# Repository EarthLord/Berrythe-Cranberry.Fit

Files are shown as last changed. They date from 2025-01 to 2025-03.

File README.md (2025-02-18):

# Berrythe

## Objective

Create a low-cost alternative for a breathing assistant toy in India by replacing the circuitry of a night light toy. The working is similar these toys in these Amazon US [shopping link 1](https://a.co/d/hcPQM95), [shopping link 2](https://a.co/d/2bBX1N4). Below is a video of the resulting breathing sequence from a retrofit night light toy.

https://github.com/user-attachments/assets/268d343a-7a08-4612-9922-748c09accf75

This open-source project is done for [Cranberry.fit](https://cranberry.fit), a company developing personalized care products to improve menstrual health.

## Repository Content

This repository contains both the hardware and firmware for Berrythe - KiCad PCB design and TI Code Composer Studio Project. The respective hardware and firmware folders contain their documentation as well.

## Specifications of toy

1. Overall, the two functional modes are
    1. Breathing mode of 4, 7, 8
    2. Yellow night light mode
2. This needs to be compatible with the toys below (Amazon India [shopping link 1](https://amzn.in/d/7s0jjhx), [shopping link 2](https://amzn.in/d/guYvsHx))

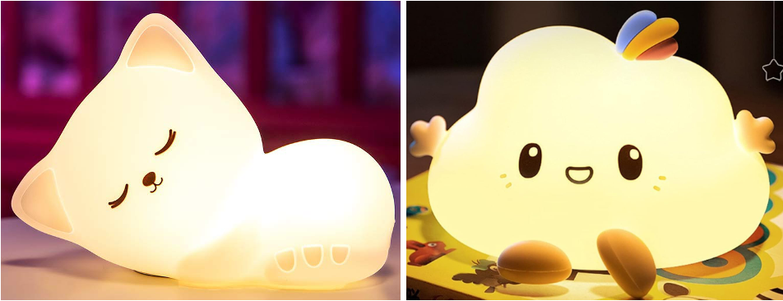
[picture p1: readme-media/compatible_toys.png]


3. Additional cost for the electronics at quantity of 1000 needs to be less than 300 INR.
4. Battery life
    1. Breathing or Night light mode need needs to be able to run at least for 8 hours on a full charge.
    2. In OFF mode the battery should last at least 6 months.

### Operations of the toy

1. Overall there are three modes for the toy, namely
    1. Power down mode (OFF)
    2. Breathing mode (BREATH)
    3. Yellow night light mode (NIGHT)
2. There is one button for user input interaction, at the bottom of the toy. The two means of interaction with this button is single-press or double-press. Double press isn’t used as it reduces good user experience. 
3. The breathing mode will be on for a time of 10 minutes, following which it’ll power down.
4. The night light mode will be on for a time of 30 minutes, following which it’ll power down.
5. The following will be the flow of operation of the toy

```mermaid
stateDiagram
  direction LR
  [*] --> OFF
  OFF --> BREATH:1-press
  BREATH --> NIGHT:1-press
  BREATH --> OFF:10 min
  NIGHT --> OFF:30 min
  NIGHT --> OFF:1-press
```
6. The breathing mode timing would be as follows to provide an overall 4, 7, 8 breathing exercise. The green and blue color intensity would change as shown below, visually changing linearly. 



| Inhale | Tr | Hold | Tr | Exhale | Tr |
| --- | --- | --- | --- | --- | --- |
| 3.8s | 0.2s | 6.8s | .2s | 7.8s | 0.2s |
7. During the transition time of 0.2s (Tr in above table) the color will shift from previous one to the next one.

## Breathing Technique’s Why and How

### Slow, controlled breathing stimulates the parasympathetic nervous system

This is the part of the nervous system that slows down activity in the body, promotes relaxation, and thus alleviates anxiety and mood changes

### Slows down heart rate, blood pressure, and oxygen consumption

This breathing technique has a low inhale-to-exhale ratio (where you only inhale for 4 seconds and exhale for 8), and requires you to hold your breath. These specific practices may increase your blood oxygen levels and lower your blood pressure. All of which contribute to a less agitated, and more relaxed state.

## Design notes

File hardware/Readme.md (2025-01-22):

# Berrythe hardware documentation

This is the hardware setup of V1 of Berrythe. The white PCB is the original PCB from the night light toy. [LP-MSPM0C1104](https://www.ti.com/tool/LP-MSPM0C1104) development kit has a XDS110 debugger and is used to program, debug and log UART to PC.

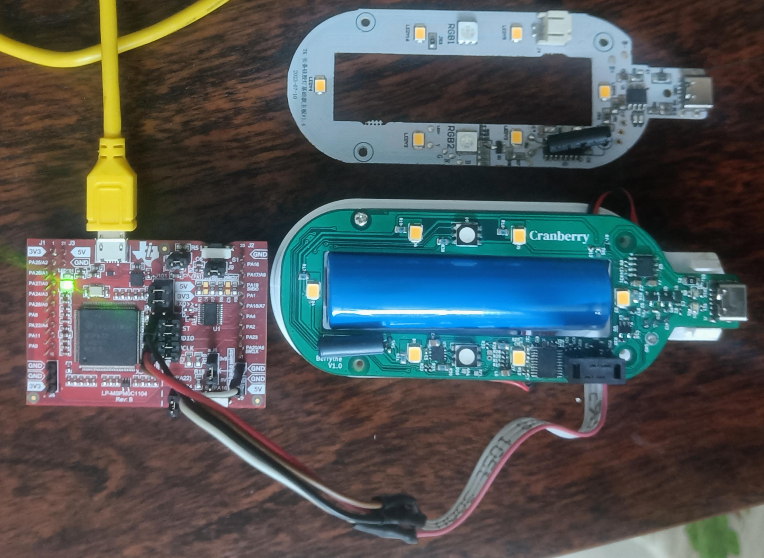
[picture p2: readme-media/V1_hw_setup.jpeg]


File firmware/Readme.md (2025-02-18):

# Berrythe firmware documentation

The overarching requirement from the firmware is specified by the state machine below.
```mermaid
stateDiagram
  direction LR
  [*] --> BREATH:Boot
  OFF --> [*]:Button press<br>to reboot
  BREATH --> NIGHT:Button press
  BREATH --> OFF:10 min
  NIGHT --> OFF:30 min
  NIGHT --> OFF:Button press
  LOW_BATTERY --> OFF:Red LED<br>indication
  NIGHT --> LOW_BATTERY: Vbat<3.5V
  BREATH --> LOW_BATTERY: Vbat<3.5V
```
## Challenges

### Code memory size
[MSPM0C1103](https://www.ti.com/product/MSPM0C1103), the target micro-controller from TI is with a ARM Cortex M0+ processor, 1 kB RAM and 8 kB Flash as it is targeted for low-cost, simple applications. The primary challenge for the firmware was to develop the application within the code space available in Flash, especially the LED gamma correction algorithm explained below. The memory usage (-Os optimization) is as shown in the table below, although it might change a bit based on the commit.

| Memory | Usage |
| --- | ----- |
| RAM (1 kB) | 12% |
| Flash (8 kB) | 84% |

### Gamma correction
Getting gamma correction to have pleasant visual transitions of LEDs and to have it fit in the 8 kB of flash needed iterations in the design. This is explained in detail further down.

## Project specific development principles
- Keep it simple - develop what's necessary for the project, not more. This project is not going to be a library for further use.
    - Important for both reliability and memory optimization.
- Use as much as possible vendor HAL driver and suitable external libraries. This would be the DriverLib from TI and  printf from Spare Time Labs 2.0.
    - One implication of this would be majority of the configuration of the peripherals of the is based on the System Configuration GUI tool from TI. The configuration is stored in a .syscfg file. Build triggers generation of a ti_msp_dl_config.c and .h file based on the .syscfg file.
- Optimize what is necessary, don't worry about the miniscule gains either in memory usage or power consumption.

## Low memory footprint printf library
Formatted prints over the UART line is an essential tool for debugging, even if the Code Composer Studio from TI along with XDS110 debugger provides complete debugging infrastructure of breakpoints, memory/variable views, and call-stacks.

[Tiny printf](http://www.sparetimelabs.com/tinyprintf/tinyprintf.php) from Spare Time Labs 2.0 is library being used, with it consuming 528 bytes on the Flash memory.

Alternatives considered were the [mpaland's printf fork maintained by eyalroz](https://github.com/eyalroz/printf) and [charlesnicholson's nanoprintf](https://github.com/charlesnicholson/nanoprintf). Both of them consume more memory than Tiny printf.

## BREATHE and NIGHT mode
The general flow of these two modes are as shown below.
```mermaid
flowchart TD
    enter(["Enter mode"]) ---> init["Mode specific<br>initialization"]
    init ---> timer["Set periodic<br>timer callback"]
    timer ---> sleep(["Sleep"])
    tim_cb(["Periodic timer<br>callback<br>Every millisecond"]) --> btn["Is button<br>pressed"]
    btn@{ shape: diam}
    btn --> |YES|next(["Start next<br>mode"])
    btn --> |NO|bat["Is<br>Bvat<3.5V"]
    bat@{ shape: diam}
    bat --> |YES|low(["Go to low<br>battery mode"])
    bat --> |NO|time["Is mode<br>timed out"]
    time@{ shape: diam}
    time --> |YES|off(["Go to low<br>OFF mode"])
    time --> |NO|mode["Mode specific<br>process"]
    mode --> sleep
```
Since in these modes the main power consumption is from the LEDs, there is less focus on optimizing the power consumption due to the MCU. The periodic timer callback wakes the MCU every millisecond. 

### BREATHE mode
Breathe mode is for the primary use of providing a breathing pattern for the user. Note that for the end user the color transition of green and blue need to appear to be changing linearly visually.
Color

|Color | Green | Purple | Blue |
|--- | ----- | --- | ---- |
|Duration | 4s | 7s | 8s |

LP5810 LED driver has an auto mode where the LED pattern needed can be programmed in it's registers via I2C, such that it can generate the pattern automatically without involvement of the MCU. This mode didn't work as expected as detailed in this [forum question](https://e2e.ti.com/support/power-management-group/power-management/f/power-management-forum/1463546/lp5810-auto-pattern-not-as-per-what-gui-shows/). Thus, the manual mode is used where every millisecond a I2C write sets the LED intensity to be set by LP5810.

As the flash memory is limited and only linear transitions of color is needed, an approach of interpolating the LED brightness for each sequence is done. This is done by specifying the start and end brightness for the red, green and blue LEDs, along with the duration of the period of this sequence in arrays. By tracking the number of periodic timer calls in each sequence, the current value to be set for each of the three LEDs is interpolated based on the start and end values.

#### Gamma Correction

A technique called Gamma Correction is need to correct the LED brightness as it is changes in to make the perception with our eyes linear. Adafruit has a good [practical article](https://learn.adafruit.com/led-tricks-gamma-correction) on this.

Gamma correction can be done by LP5810, although this feature is not used. This is because it has only a 8-bit value to work on. Since initially the value to be set is generated as a 16-bit value, gamma correction is also done with this and then down-scaled to 8 bit value. This creates a smoother transition. This helped in fixing the blocky transition of the colors when using the inbuilt gamma correction of LP5810. 

To avoid usage of float variables as well as 'to the power of' operation of floats, the gamma value used for gamma correction is 2.0. This would need additional 2-3 kB of libraries for the float operations and would exceed the 8kB flash size. Using a gamma value of 2 enables working only on integers and gives a decent gamma correction visually.

### NIGHT mode
In night mode one of the generic timers (TIMG) is used to operate the warm white LEDs at a 10% duty cycle. LP5810 is disabled on the start of this mode. 

## OFF mode and low power considerations
In all modes except OFF mode, the MCU operates in SLEEP mode, where only the processor 

| Mode | Low power | Operation |
| --- | ----- | ----- |
| Other modes | SLEEP0 | Only processor is disabled |
| OFF mode | STANDBY1  | Only GPIO and Timers (32kHz) are enabled |

Before initiating STANDBY1 low power state in the OFF mode, LP5810 is disabled and the MOSFET driving the night lights is turned off to remove their power consumption.

On waking up from OFF mode, the MCU does a software reset to start afresh in the BREATHE mode. This makes the firmware development easier since each mode's states don't have to be maintained across as they can be run at most once.

## Button sensing
To have better user experience, it was decided to only have user's perform a single press and not have any significance for double, triple or long press. For both debouncing and filtering out unintentional taps, the button press needed to be in the form of the below pattern. 

```mermaid
---
config:
  theme: neo
---
timeline
    At least 25 ms : Released
    At least 25 ms : Pressed
    At least 25 ms : Released
    100 ms : Valid button press
```

## Battery and charging check for low power mode
Voltage dividers are used to measure the battery voltage and the USB input voltage by the ADC of the MCU.  The different modes for the battery are computed as per the below table.

| State | USB Power | Battery voltage |
| ---- | --- | --- |
| CHARGING | Present | Don't care |
| NORMAL | Absent | Greater than 3.5V |
| LOW | Absent | Lower than 3.5V |

Battery and USB power measurements are done approximately every 16s. On sensing LOW battery state, irrespective of the current mode of operation, LOW_BATTERY mode is entered. In this mode a short 3s sequence of red LED flashing is shown to user to indicate the mode. After this it goes to the OFF mode to conserve battery power.

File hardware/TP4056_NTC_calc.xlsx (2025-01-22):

Vin | 5 | V
Vtemp,IH | 0.8 | V
Vtemp,IL | 0.45 | V
Rntc @ 25C | 10000 | Ohm
RH ntc @ 45C | 4911 | Ohm
RL ntc @ 2C | 25000 | Ohm
R1 | 300000 | Ohm
R2 | 18000 | Ohm
VtempIH eq | 0.7977819009
VtempIL eq | 0.4515138219

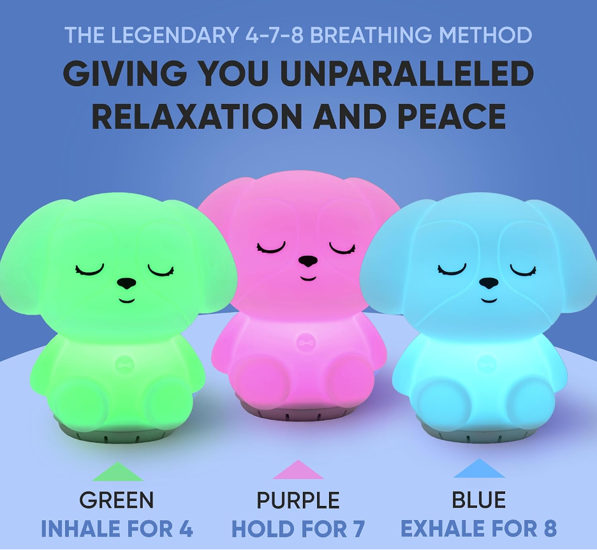
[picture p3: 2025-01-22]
readme-media/breathing_toys.png

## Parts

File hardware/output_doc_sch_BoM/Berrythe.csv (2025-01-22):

No | Reference | Value | Footprint | Qty | DNP | PN
1 | BT1 | Battery_Cell | Berrythe-footprints:JST_PH_S2B-PH-K_1x02_P2.00mm_Horizontal | 1 |  | S2B-PH-K-S
2 | C1,C2,C4,C6 | 10u | Berrythe-footprints:C_0805_2012Metric | 4 |  | CL21A106KOQNNNE
3 | C3,C5,C7,C9,C10,C14 | 100n | Berrythe-footprints:C_0402_1005Metric | 6 |  | CL05B104KO5NNND
4 | C8,C11,C12,C13 | 10n | Berrythe-footprints:C_0402_1005Metric | 4 |  | CL05B103KO5NNNC
5 | D1 | Green LED | Berrythe-footprints:LED_0603_1608Metric | 1 |  | QBLP601-YG1-2943
6 | D2 | Red LED | Berrythe-footprints:LED_0603_1608Metric | 1 |  | SML-D12U1WT86
7 | D3,D4,D5,D6,D7,D8 | Warm LED | Berrythe-footprints:LED_PLCC_2835 | 6 |  | JB2835BWT-N-U35EA0000-N000P001
8 | D9,D10 | RGB LED | Berrythe-footprints:LED_RGB_5050-6 | 2 |  | QLSP08RGB_B
9 | D11 | D5V0S1U2LP | Berrythe-footprints:D_SOD-882D | 1 |  | D5V0S1U2LP-7B
10 | J1 | USB_C_Receptacle_PowerOnly_6P | Berrythe-footprints:AMPHENOL_10164359-00011LF | 1 |  | 10164359-00011LF
11 | J2 | TactileSw Conn | Berrythe-footprints:Molex_Pico-Clasp_501331-0207_1x02-1MP_P1.00mm_Vertical | 1 |  | 530470210
12 | J3 | TactileSw Conn | Berrythe-footprints:Molex_PicoBlade_53047-0210_1x02_P1.25mm_Vertical | 1 |  | 5013310207
13 | Q1,Q2,Q3 | DMN2024U | Berrythe-footprints:SOT-23 | 3 |  | DMN2024U-7
14 | R1 | 0E | Berrythe-footprints:R_1206_3216Metric | 1 |  | RC1206JR-130RL
15 | R2,R6,R8,R9,R14,R15,R28,R29 | 2k | Berrythe-footprints:R_0402_1005Metric | 8 |  | RC0402FR-072KL
16 | R3 | 330E | Berrythe-footprints:R_0402_1005Metric | 1 |  | RC0402FR-07330RL
17 | R4,R5 | 5M1 | Berrythe-footprints:R_0402_1005Metric | 2 |  | RC0402FR-075M1L
18 | R10,R11,R12,R35 | 5k1 | Berrythe-footprints:R_0402_1005Metric | 4 |  | RC0402FR-075K1L
19 | R13,R26,R30,R31,R34 | 47k | Berrythe-footprints:R_0402_1005Metric | 5 |  | RC0402FR-0747KL
20 | R16,R17,R18,R19,R20,R21,R38,R39 | 24E | Berrythe-footprints:R_0805_2012Metric | 8 |  | RK73H2ATTD24R0F
21 | R22,R23,R24,R27,R32,R33 | 10E | Berrythe-footprints:R_0402_1005Metric | 6 |  | RC0402FR-0710RL
22 | R37 | 0E | Berrythe-footprints:R_0402_1005Metric | 1 |  | RC0402JR-070RL
23 | SW1 | SW_Vibr | Berrythe-footprints:SW-18010P | 1 |  | 1766
24 | U1 | BQ29737 | Berrythe-footprints:WSON-6_1.5x1.5mm_P0.5mm | 1 |  | BQ29737DSER
25 | U2 | TP4056 | Berrythe-footprints:SOIC-8-1EP_3.9x4.9mm_P1.27mm_EP2.41x3.3mm | 1 |  | TPB4056B2X-ES1R
26 | U3 | LP5810D | Berrythe-footprints:WSON8-LP5810 | 1 |  | LP5810DDSDR
27 | U4 | MSPS003FxSPW20R | Berrythe-footprints:TSSOP-20_4.4x6.5mm_P0.65mm | 1 |  | MSPS003F4SPW20R
28 | U5 | TCR2LF33,LM(CT | Package_TO_SOT_SMD:SOT-23-5 | 1 |  | TCR2LF33,LM(CT

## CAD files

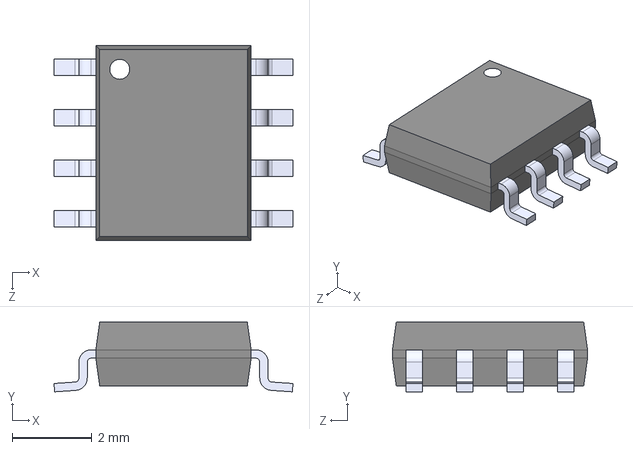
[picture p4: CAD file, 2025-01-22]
hardware/3D_models/TP4056-42-ESOP8.step
6.00 x 1.75 x 4.90 mm

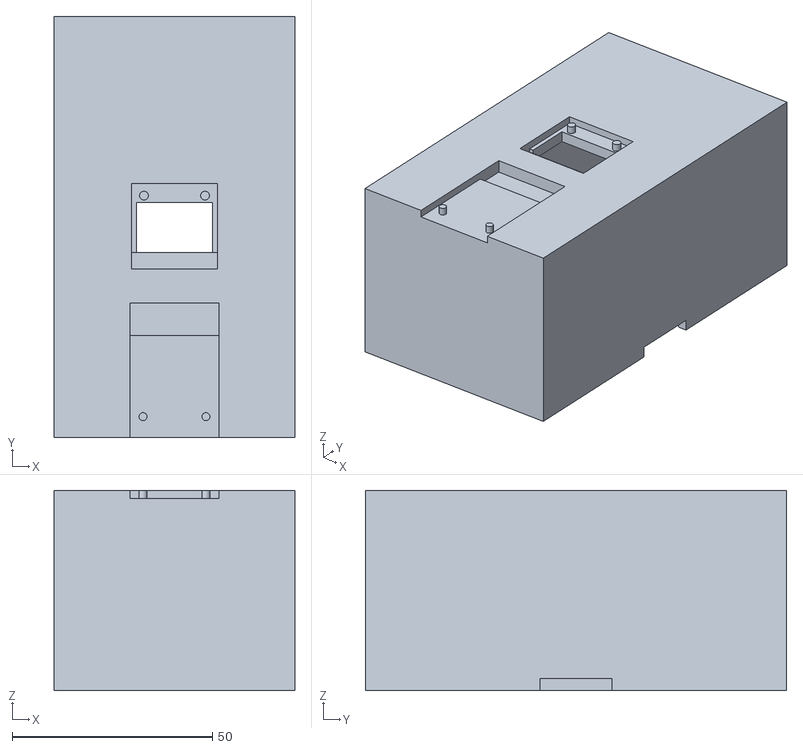
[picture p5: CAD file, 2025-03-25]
test-jig/Jig_PCB_holder_top.stl
60.0 x 105.0 x 50.0

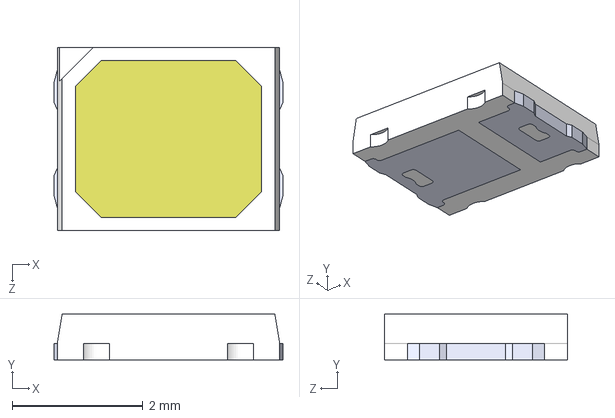
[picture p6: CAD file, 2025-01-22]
hardware/3D_models/JB2835BWT-3DModel.STEP
3.50 x 0.7 x 2.80 mm

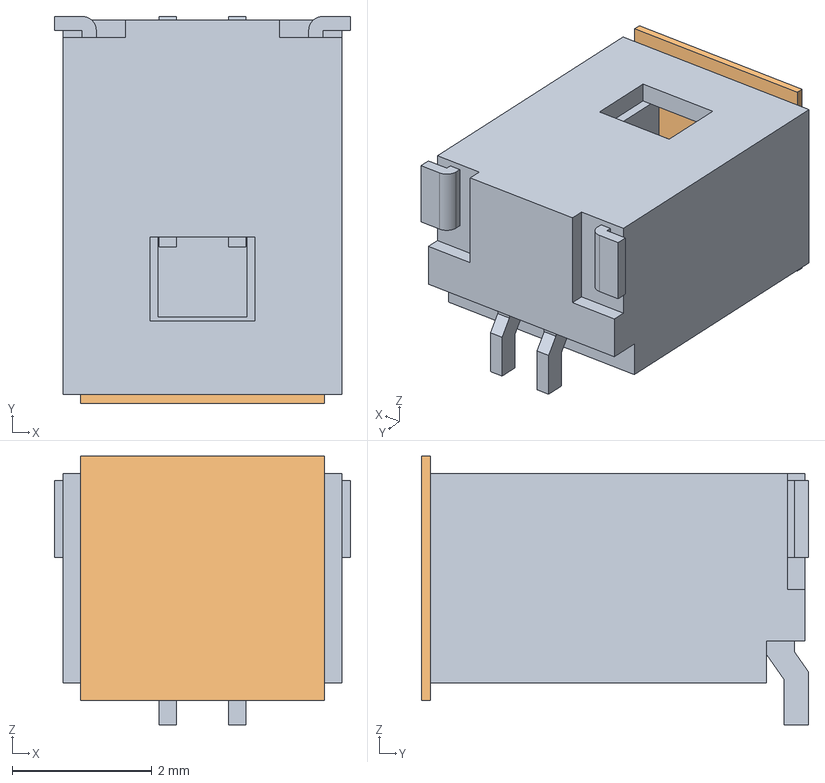
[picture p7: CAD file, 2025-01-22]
hardware/3D_models/5013310207.stp
4.24 x 5.54 x 3.85 mm

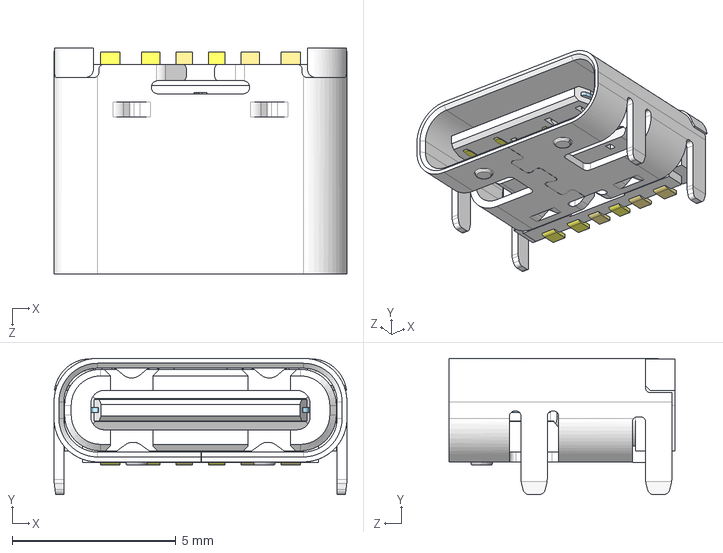
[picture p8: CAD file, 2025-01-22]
hardware/3D_models/10164359-00011LF.step
8.94 x 4.16 x 6.90 mm

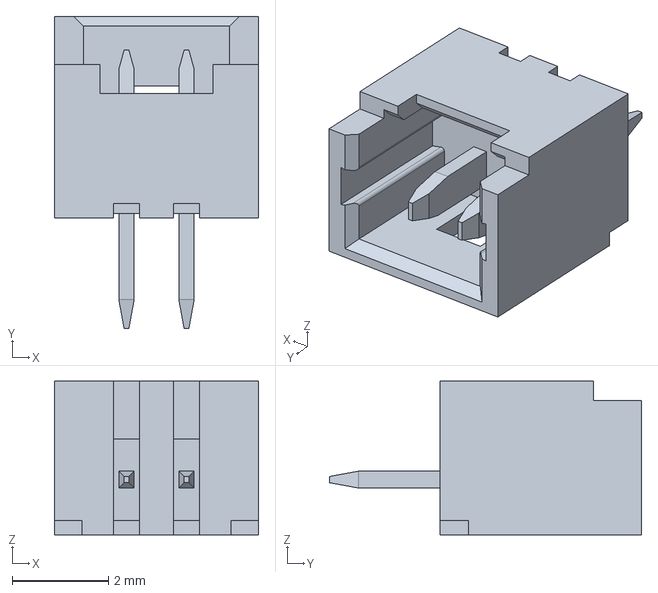
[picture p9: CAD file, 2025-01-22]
hardware/3D_models/530470210-3DModel.STEP
4.25 x 6.50 x 3.20 mm

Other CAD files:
test-jig/Jig_PCB_holder_bottom.FCStd
test-jig/Jig_PCB_holder_bottom.stl

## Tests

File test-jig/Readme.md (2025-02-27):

```mermaid
---
config:
  themeCSS: |
    #edge4, #edge6, #edge7, #edge8 { stroke: red; stroke-width: 2px; }
    #edge9 { stroke: green ; stroke-width: 2px;  stroke-dasharray="10,5"; }
---
stateDiagram
  direction LR
  idR --> XDS110:USB
  XDS110 --> Berrythe:SWD,UART
  idR --> Berrythe:Button GPIO
  idC --> idR:I2C
  idAC --> idP1:240V AC
  idR --> MOSFET:GPIO
  idP1 --> idR:5V
  idP1 --> MOSFET:5V
  MOSFET --> Berrythe:5V USB
  Berrythe --> idC:LED light
  idR:R-Pi 3B+
  idR:Capacitive Screen
  Berrythe:Device Under Test
  Berrythe:Berrythe
  idC:Color sensor
  idAC:AC mains
  idP1:5V Adapter 7A

```

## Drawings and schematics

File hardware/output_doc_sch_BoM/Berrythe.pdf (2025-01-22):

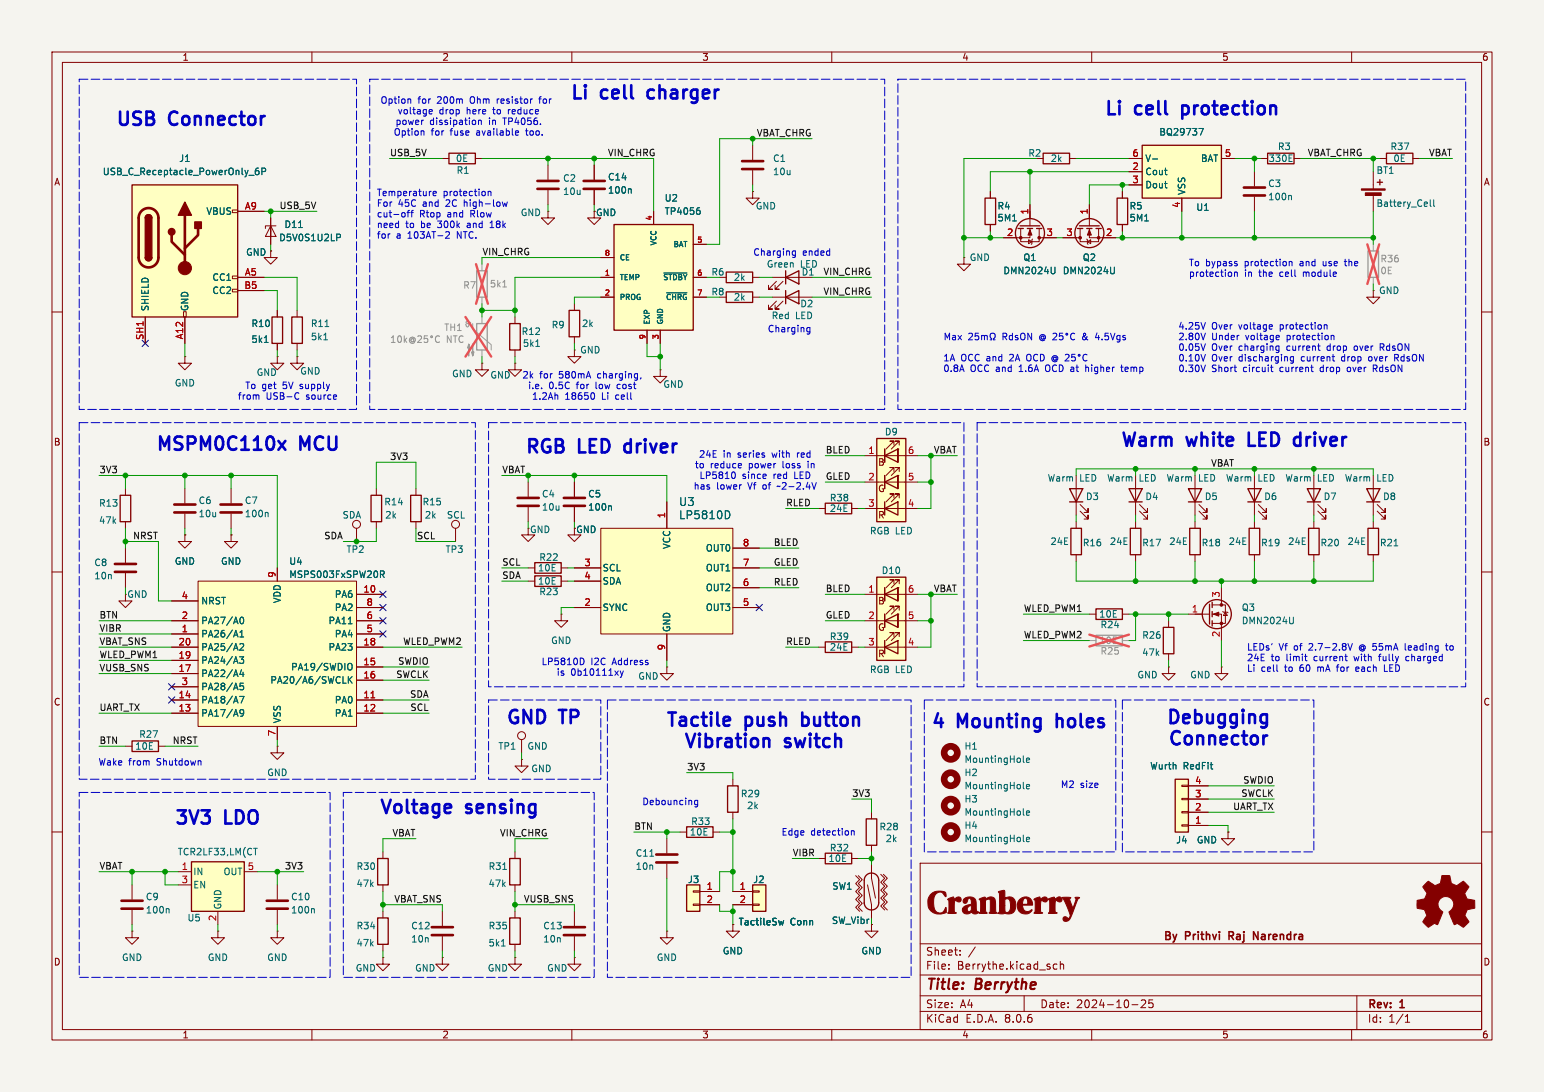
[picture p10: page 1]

0.8A OCC and 1.6A OCD at higher temp Li cell protection

need to be 300k and 18k
Charging ended Voltage sensing

4 BAT 5 ~{STDBY}6 ~{CHRG}7 CE 8 EXP

Connector Max þÿ25m©RdsON @ þÿ25°C& 4.5Vgs 1A OCC and 2A OCD @ þÿ25°C

Warm white LED driver

Li cell to 60 mA for each LED MSPM0C110x MCU

24E in series with red
to reduce power loss in
LP5810 since red LED
has lower Vf of ~2-2.4V

1 SYNC 2 SCL 3 SDA 4 OUT3 5 OUT2 6 OUT1 7 OUT0 8 GND

24E to limit current with fully charged

Edge detection Tactile push button
Vibration switch

H3 MountingHole H2 MountingHole H1 MountingHole H4 MountingHole

2 EN 3 OUT 5 U5 TCR2LF33,LM(CT C10

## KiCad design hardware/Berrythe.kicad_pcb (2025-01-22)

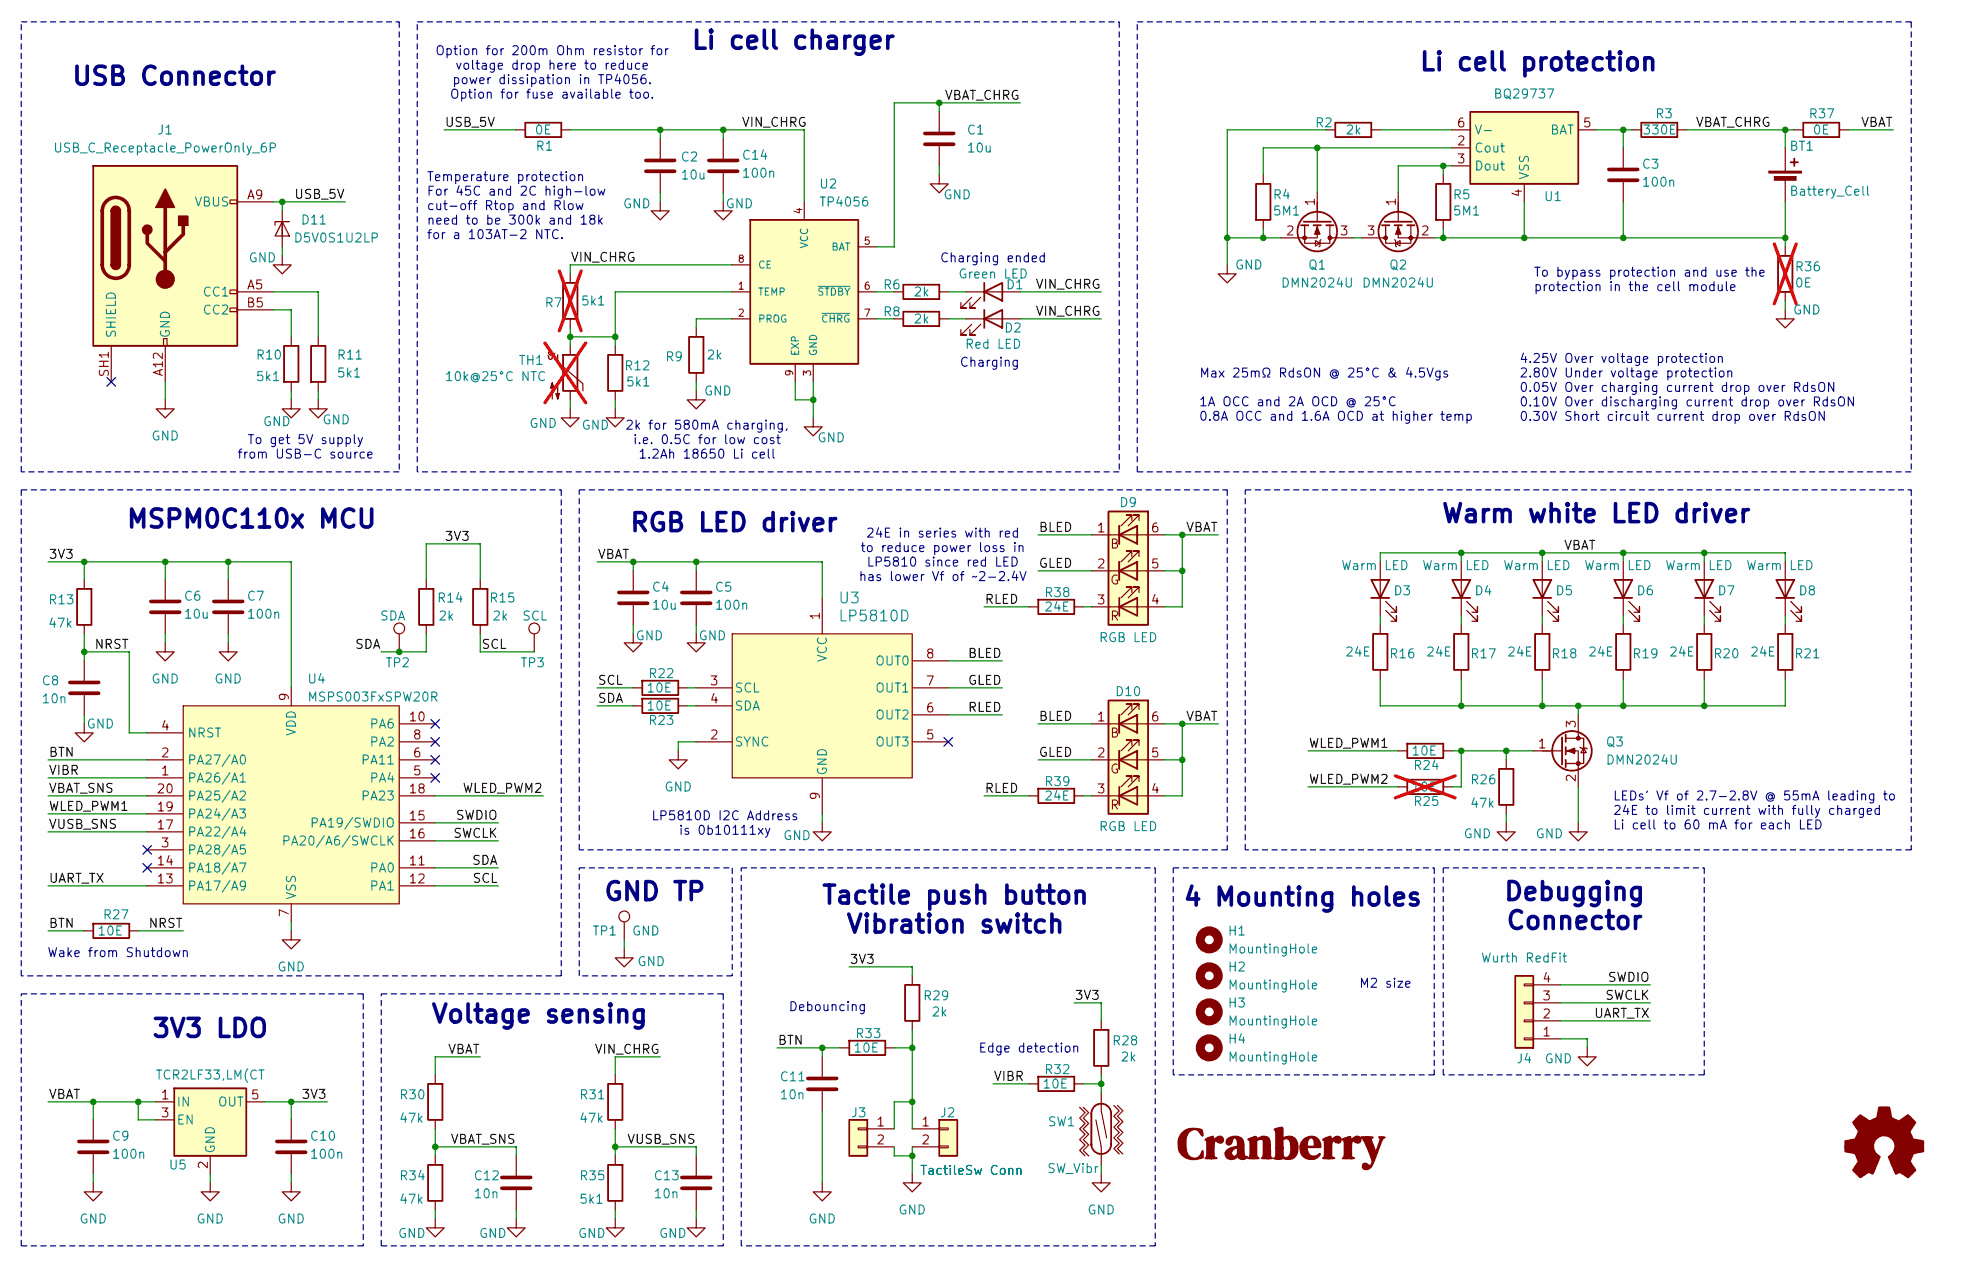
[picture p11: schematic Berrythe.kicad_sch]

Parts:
BT1: Battery_Cell; JST_PH_S2B-PH-K_1x02_P2.00mm_Horizontal
C1, C2, C4, C6: 10u; C_0805_2012Metric
C3, C5, C7, C9, C10, C14: 100n; C_0402_1005Metric
C8, C11, C12, C13: 10n; C_0402_1005Metric
D1: Green LED; LED_0603_1608Metric
D2: Red LED; LED_0603_1608Metric
D3, D4, D5, D6, D7, D8: Warm LED; LED_PLCC_2835
D9, D10: RGB LED; LED_RGB_5050-6
D11: D5V0S1U2LP; D_SOD-882D
H1, H2, H3, H4: MountingHole; MountingHole_2.2mm_M2
J1: USB_C_Receptacle_PowerOnly_6P; AMPHENOL_10164359-00011LF
J2: TactileSw Conn; Molex_Pico-Clasp_501331-0207_1x02-1MP_P1.00mm_Vertical
J3: TactileSw Conn; Molex_PicoBlade_53047-0210_1x02_P1.25mm_Vertical
J4: Wurth RedFit; 490107670412_DEBUGGING
Q1, Q2, Q3: DMN2024U; SOT-23
R1: 0E; R_1206_3216Metric
R2, R6, R8, R9, R14, R15, R28, R29: 2k; R_0402_1005Metric
R3: 330E; R_0402_1005Metric
R4, R5: 5M1; R_0402_1005Metric
R7: 5k1; R_0402_1005Metric; not fitted
R10, R11, R12, R35: 5k1; R_0402_1005Metric
R13, R26, R30, R31, R34: 47k; R_0402_1005Metric
R16, R17, R18, R19, R20, R21, R38, R39: 24E; R_0805_2012Metric
R22, R23, R24, R27, R32, R33: 10E; R_0402_1005Metric
R25: 10E; R_0402_1005Metric; not fitted
R36: 0E; R_0402_1005Metric; not fitted
R37: 0E; R_0402_1005Metric
SW1: SW_Vibr; SW-18010P
TH1: 10k@25°C NTC; R_0603_1608Metric; not fitted
TP1: GND; TestPoint_THTPad_D2.5mm_Drill1.2mm
TP2: SDA; TestPoint_Pad_1.0x1.0mm
TP3: SCL; TestPoint_Pad_1.0x1.0mm
U1: BQ29737; WSON-6_1.5x1.5mm_P0.5mm
U2: TP4056; SOIC-8-1EP_3.9x4.9mm_P1.27mm_EP2.41x3.3mm
U3: LP5810D; WSON8-LP5810
U4: MSPS003FxSPW20R; TSSOP-20_4.4x6.5mm_P0.65mm
U5: TCR2LF33,LM(CT; SOT-23-5

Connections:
/3V3: C6.1, C7.1, C10.1, R13.2, R14.2, R15.2, R28.2, R29.2, U4.9 (VDD), U5.5 (OUT)
/BLED: D9.1 (RK), D10.1 (RK), U3.8 (OUT0)
/BTN: C11.1, R27.2, R33.2, U4.2 (PA27/A0)
/GLED: D9.2 (GK), D10.2 (GK), U3.7 (OUT1)
/NRST: C8.1, R13.1, R27.1, U4.4 (NRST)
/RLED: R38.2, R39.2, U3.6 (OUT2)
/SCL: R15.1, R22.2, TP3.1, U4.12 (PA1)
/SDA: R14.1, R23.2, TP2.1, U4.11 (PA0)
/SWCLK: J4.3, U4.16 (PA20/A6/SWCLK)
/SWDIO: J4.4, U4.15 (PA19/SWDIO)
/UART_TX: J4.2, U4.13 (PA17/A9)
/USB_5V: D11.1 (K1), J1.A9 (VBUS), J1.B9 (VBUS), R1.1
/VBAT: C4.1, C5.1, C9.1, D3.2 (A), D4.2 (A), D5.2 (A), D6.2 (A), D7.2 (A), D8.2 (A), D9.4 (BA), D9.5 (GA), D9.6 (RA), D10.4 (BA), D10.5 (GA), D10.6 (RA), R30.2, R37.2, U3.1 (VCC), U5.1 (IN), U5.3 (EN)
/VBAT_CHRG: BT1.2 (+), C1.1, R3.2, R37.1, U2.5 (BAT)
/VBAT_SNS: C12.1, R30.1, R34.2, U4.20 (PA25/A2)
/VIBR: R32.2, U4.1 (PA26/A1)
/VIN_CHRG: C2.1, C14.1, D1.2 (A), D2.2 (A), R1.2, R7.2, R31.2, U2.4 (VCC), U2.8 (CE)
/VUSB_SNS: C13.1, R31.1, R35.2, U4.17 (PA22/A4)
/WLED_PWM1: R24.2, U4.19 (PA24/A3)
/WLED_PWM2: R25.2, U4.18 (PA23)
GND: C1.2, C2.2, C4.2, C5.2, C6.2, C7.2, C8.2, C9.2, C10.2, C11.2, C12.2, C13.2, C14.2, D11.2 (A), J1.A12 (GND), J1.B12 (GND), J2.2, J3.2, J4.1, Q1.2 (S), Q3.2 (S), R2.1, R4.2, R9.1, R10.2, R11.2, R12.1, R26.1, R34.1, R35.1, R36.2, SW1.2, TH1.2, TP1.1, U2.3 (GND), U2.9 (EXP), U3.2 (SYNC), U3.9 (GND), U4.7 (VSS), U5.2 (GND)
unnamed: BT1.1 (-), C3.2, Q2.2 (S), R5.2, R36.1, U1.4 (VSS)
unnamed: D1.1 (K), R6.2
unnamed: D2.1 (K), R8.2
unnamed: D3.1 (K), R16.2
unnamed: D4.1 (K), R17.2
unnamed: D5.1 (K), R18.2
unnamed: D6.1 (K), R19.2
unnamed: D7.1 (K), R20.2
unnamed: D8.1 (K), R21.2
unnamed: D9.3 (BK), R38.1
unnamed: D10.3 (BK), R39.1
unnamed: J1.A5 (CC1), R11.1
unnamed: J1.B5 (CC2), R10.1
unnamed: J2.1, J3.1, R29.1, R33.1
unnamed: Q1.3 (D), Q2.3 (D)
unnamed: Q1.1 (G), R4.1, U1.2 (Cout)
unnamed: Q2.1 (G), R5.1, U1.3 (Dout)
unnamed: Q3.3 (D), R16.1, R17.1, R18.1, R19.1, R20.1, R21.1
unnamed: Q3.1 (G), R24.1, R25.1, R26.2
unnamed: R28.1, R32.1, SW1.1
unnamed: C3.1, R3.1, U1.5 (BAT)
unnamed: R2.2, U1.6 (V-)
unnamed: R9.2, U2.2 (PROG)
unnamed: R7.1, R12.2, TH1.1, U2.1 (TEMP)
unnamed: R8.1, U2.7 (~CHRG)
unnamed: R6.1, U2.6 (~STDBY)
unnamed: R22.1, U3.3 (SCL)
unnamed: R23.1, U3.4 (SDA)

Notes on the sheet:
Charging ended
Debouncing
Option for 200m Ohm resistor for voltage drop here to reduce power dissipation in TP4056. Option for fuse available too.
LEDs' Vf of 2.7-2.8V @ 55mA leading to 24E to limit current with fully charged Li cell to 60 mA for each LED
2k for 580mA charging, i.e. 0.5C for low cost 1.2Ah 18650 Li cell
4.25V Over voltage protection 2.80V Under voltage protection 0.05V Over charging current drop over RdsON 0.10V Over discharging current drop over RdsON 0.30V Short circuit current drop over RdsON
GND TP
Debugging Connector
Tactile push button Vibration switch
4 Mounting holes
Warm white LED driver
Li cell protection
Max 25mΩ RdsON @ 25°C & 4.5Vgs
USB Connector
RGB LED driver
Edge detection
M2 size
Voltage sensing
Li cell charger
Charging
To get 5V supply from USB-C source
To bypass protection and use the protection in the cell module
MSPM0C110x MCU
LP5810D I2C Address is 0b10111xy
24E in series with red to reduce power loss in LP5810 since red LED has lower Vf of ~2-2.4V
Temperature protection For 45C and 2C high-low cut-off Rtop and Rlow need to be 300k and 18k for a 103AT-2 NTC.
3V3 LDO
1A OCC and 2A OCD @ 25°C 0.8A OCC and 1.6A OCD at higher temp
Wake from Shutdown

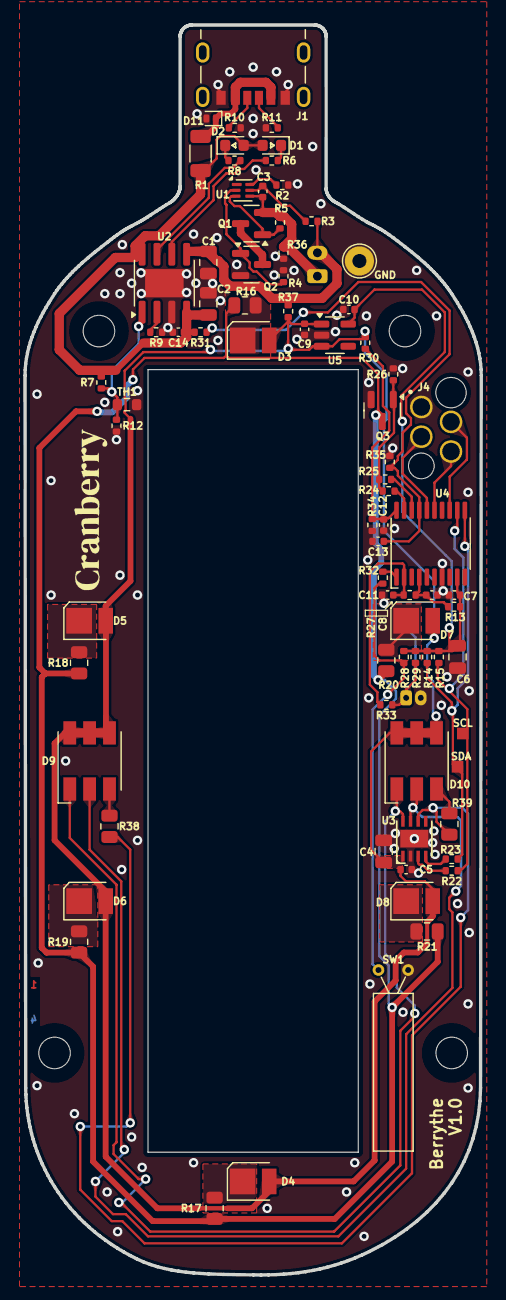
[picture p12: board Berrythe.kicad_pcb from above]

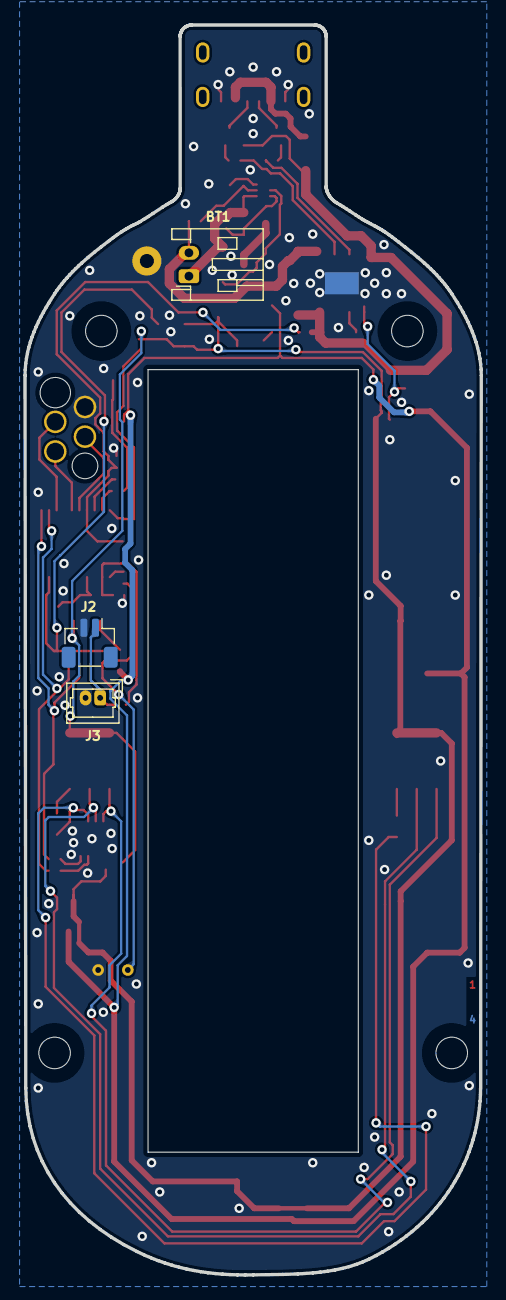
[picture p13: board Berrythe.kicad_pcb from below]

Board: 4 copper layers, 39.1 x 107.0 mm, 86 parts (3 on the bottom side), 49 nets.

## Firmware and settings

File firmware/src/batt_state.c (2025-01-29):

/*
 * Copyright (c) 2025, Cranberry Fit (Empower Digital Health Pvt Ltd)
 * All rights reserved.
 *
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
 * THIS SOFTWARE IS PROVIDED BY THE COPYRIGHT HOLDERS AND CONTRIBUTORS "AS IS"
 * AND ANY EXPRESS OR IMPLIED WARRANTIES, INCLUDING, BUT NOT LIMITED TO, THE
 * IMPLIED WARRANTIES OF MERCHANTABILITY AND FITNESS FOR A PARTICULAR PURPOSE ARE
 * DISCLAIMED. IN NO EVENT SHALL THE COPYRIGHT HOLDER OR CONTRIBUTORS BE LIABLE
 * FOR ANY DIRECT, INDIRECT, INCIDENTAL, SPECIAL, EXEMPLARY, OR CONSEQUENTIAL
 * DAMAGES (INCLUDING, BUT NOT LIMITED TO, PROCUREMENT OF SUBSTITUTE GOODS OR
 * SERVICES; LOSS OF USE, DATA, OR PROFITS; OR BUSINESS INTERRUPTION) HOWEVER
 * CAUSED AND ON ANY THEORY OF LIABILITY, WHETHER IN CONTRACT, STRICT LIABILITY,
 * OR TORT (INCLUDING NEGLIGENCE OR OTHERWISE) ARISING IN ANY WAY OUT OF THE USE
 * OF THIS SOFTWARE, EVEN IF ADVISED OF THE POSSIBILITY OF SUCH DAMAGE.
 */

#include "batt_state.h"
#include "ti/driverlib/m0p/dl_core.h"
#include "ti_msp_dl_config.h"
#include "stdint.h"
#include "tfp_printf.h"

#define DELAY_1_US_COUNT        (CPUCLK_FREQ/1000000)
#define ADC_SAMPLING_DELAY_US   (450)

#define VBAT_CUTOFF_THRESHOLD_MV    (3500)
#define VIN_CUTOFF_THRESHOLD_MV     (4800)

//Voltage divider of 47k and 47k
//Voltage drops by a ratio of (47/94)
//Conversion to 2.5V reference 10 bit ADC value by
//THRESHOLD*(47/94)*(1024)/(2500)
#define VBAT_ADC_VALUE_CUTOFF       ((VBAT_CUTOFF_THRESHOLD_MV*128)/(625))

//Voltage divider of 5.1k and 47k
//Voltage drops by a ratio of (5.1/52.1)
//Conversion to 2.5V reference 10 bit ADC value by
//THRESHOLD*(5.1/52.1)*(1024)/(2500)
#define VIN_ADC_VALUE_CUTOFF       ((VIN_CUTOFF_THRESHOLD_MV*13056)/(325625))

batt_state_t batt_state_get(void)
{
    int16_t batt_value, usb_vin_value;

    /* Get calibrated ADC offset - workaround for ADC_ERR_06 */
    int16_t ADC_offset = 
        DL_ADC12_getADCOffsetCalibration(ADC12_0_ADCMEM_VBAT_REF_VOLTAGE_V);

    DL_ADC12_startConversion(ADC12_0_INST);
    
    delay_cycles(500*DELAY_1_US_COUNT);
    
    //This wasn't working, not sure why
#if 0
    while(ADC12_STATUS_BUSY_ACTIVE == 
            (DL_ADC12_getStatus(ADC12_0_INST) & ADC12_STATUS_BUSY_MASK)){}
#endif

    batt_value = DL_ADC12_getMemResult(ADC12_0_INST, ADC12_0_ADCMEM_VBAT);
    usb_vin_value = DL_ADC12_getMemResult(ADC12_0_INST, ADC12_0_ADCMEM_VUSB);

    DL_ADC12_enableConversions(ADC12_0_INST);

    batt_value = batt_value + ADC_offset;
    usb_vin_value = usb_vin_value + ADC_offset;

    tfp_printf("Conv %d, %d\r\n", (batt_value*625)/128, usb_vin_value);

    //Valid USB Vin voltage above 4.8V
    if(usb_vin_value > VIN_ADC_VALUE_CUTOFF)
    {
        return BATT_CHARGING;
    }
    //When not charging, battery voltage above 3.5V
    //corresponding to about 10% SoC
    else if (batt_value > VBAT_ADC_VALUE_CUTOFF)
    {
        return BATT_NORMAL;
    } else 
    {
        return BATT_LOW;
    }
}

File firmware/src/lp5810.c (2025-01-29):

/*
 * Copyright (c) 2025, Cranberry Fit (Empower Digital Health Pvt Ltd)
 * All rights reserved.
 *
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
 * THIS SOFTWARE IS PROVIDED BY THE COPYRIGHT HOLDERS AND CONTRIBUTORS "AS IS"
 * AND ANY EXPRESS OR IMPLIED WARRANTIES, INCLUDING, BUT NOT LIMITED TO, THE
 * IMPLIED WARRANTIES OF MERCHANTABILITY AND FITNESS FOR A PARTICULAR PURPOSE ARE
 * DISCLAIMED. IN NO EVENT SHALL THE COPYRIGHT HOLDER OR CONTRIBUTORS BE LIABLE
 * FOR ANY DIRECT, INDIRECT, INCIDENTAL, SPECIAL, EXEMPLARY, OR CONSEQUENTIAL
 * DAMAGES (INCLUDING, BUT NOT LIMITED TO, PROCUREMENT OF SUBSTITUTE GOODS OR
 * SERVICES; LOSS OF USE, DATA, OR PROFITS; OR BUSINESS INTERRUPTION) HOWEVER
 * CAUSED AND ON ANY THEORY OF LIABILITY, WHETHER IN CONTRACT, STRICT LIABILITY,
 * OR TORT (INCLUDING NEGLIGENCE OR OTHERWISE) ARISING IN ANY WAY OUT OF THE USE
 * OF THIS SOFTWARE, EVEN IF ADVISED OF THE POSSIBILITY OF SUCH DAMAGE.
 */

#include "lp5810.h"
#include "src/tfp_printf.h"
#include "ti_msp_dl_config.h"
#include "tfp_printf.h"
#include "string.h"

/* 'D' variant of LP5810 I2C address except all status registers  */
#define LP5810D_I2C_TARGET_ADDRESS      (0x5C)   //0b1011100

/* 'D' variant of LP5810 I2C address for 0x3xx registers, mainly status  */
#define LP5810D_I2C_TARGET_ADDRESS_0x3xx    (0x5F)   //0b1011111

/* Broadcast address for LP5810 - 8 bit data address*/
#define LP5810_I2C_BROADCAST_ADDRESS    (0x6C)   //0b1101100

/* Broadcast address for LP5810 - 10 bit data address for register 0x3xx */
#define LP5810_I2C_BROADCAST_ADDRESS_0x3xx  (0x6F)   //0b1101111

#define LED_BLUE_INTENSITY_PERCENTAGE   (100)
#define LED_GREEN_INTENSITY_PERCENTAGE  (75)
#define LED_RED_INTENSITY_PERCENTAGE    (100)

#define LED_BLUE_INTENSITY_DC_VALUE     ((LED_BLUE_INTENSITY_PERCENTAGE*255)/100)
#define LED_GREEN_INTENSITY_DC_VALUE    ((LED_GREEN_INTENSITY_PERCENTAGE*255)/100)
#define LED_RED_INTENSITY_DC_VALUE      ((LED_RED_INTENSITY_PERCENTAGE*255)/100)

#define LP5810_AUTO_CONTROL_START_ADRS  (0x80)

//Only comments are the default values on boot, so not writing to them
static const uint8_t lp5810_dev_config_3to5[] = 
{
    //Config 0 - max current set to 25.5 mA
    //Config 1 - PWM freq set to 24 kHz
    0x04,   //Config 3 address
#if LP5810_AUTO_MODE
    0x07,   //Config 3 - Enable auto mode for LED 0, 1, 2
#else
    0x00,   //Config 3 - Leave in manual mode for LED 0, 1, 2
#endif
    0x00,   //Config 4 - Reserved
    0x00,   //Config 5 - Disable exponential brightness curve for LED 0, 1, 2
    //Config 7 - All PWM phases are forward aligned
    //Config 11 - VSync is set to input and blank time is 1us
};

static const uint8_t lp5810_dev_config_12[] = 
{
    0x0D,   //Config 12 address
    0x0F,   //Config 12 - Enable LED open & short detection to shutdown current sink on both
            //Short detection threshold of 0.65 of VCC
};

static const uint8_t lp5810_led_en1[] = 
{
    0x20,   //LED EN1 address
    0x07,   //LED EN1 - Enable LED 0, 1 and 2
};

static const uint8_t lp5810_auto_dc[] = 
{
    0x50,   //Auto DC0 address
    LED_BLUE_INTENSITY_DC_VALUE,   //Auto DC0 percentage
    LED_GREEN_INTENSITY_DC_VALUE,  //Auto DC1 percentage
    LED_RED_INTENSITY_DC_VALUE,    //Auto DC2 percentage
};

static const uint8_t lp5810_manual_dc[] = 
{
    0x30,   //Manual DC0 address
    LED_BLUE_INTENSITY_DC_VALUE,   //Manual DC0 percentage
    LED_GREEN_INTENSITY_DC_VALUE,  //Manual DC1 percentage
    LED_RED_INTENSITY_DC_VALUE,    //Manual DC2 percentage
};

#if LP5810_AUTO_MODE
#if 0
static const uint8_t lp5810_auto_control[] = 
{
    0x00, //led0_pause_time
    0x1F, //led0_playback times
    0x00, //led0_aeu1/pwm1
    0x00, //led0_aeu1/pwm2
    0xFF, //led0_aeu1/pwm3
    0xFF, //led0_aeu1/pwm4
    0xFF, //led0_aeu1/pwm5
    0x2B, //led0_aeu1/slope_time1
    0x2E, //led0_aeu1/slope_time2
    0x00, //led0_aeu1/pt1
    0xFF, //led0_aeu2/pwm1
    0x00, //led0_aeu2/pwm2
    0x00, //led0_aeu2/pwm3
    0x00, //led0_aeu2/pwm4
    0x00, //led0_aeu2/pwm5
    0x0F, //led0_aeu2/slope_time1
    0x00, //led0_aeu2/slope_time2
    0x00, //led0_aeu2/pt1
    0x00, //led0_aeu3/pwm1
    0x00, //led0_aeu3/pwm2
    0x00, //led0_aeu3/pwm3
    0x00, //led0_aeu3/pwm4
    0x00, //led0_aeu3/pwm5
    0x00, //led0_aeu3/slope_time1
    0x00, //led0_aeu3/slope_time2
    0x00, //led0_aeu3/pt1
    0x00, //led1_pause time
    0x1F, //led1_playback times
    0x00, //led1_aeu1/pwm1
    0xFF, //led1_aeu1/pwm2
    0x00, //led1_aeu1/pwm3
    0x00, //led1_aeu1/pwm4
    0x00, //led1_aeu1/pwm5
    0x2B, //led1_aeu1/slope_time1
    0x2E, //led1_aeu1/slope_time2
    0x00, //led1_aeu1/pt1
    0x00, //led1_aeu2/pwm1
    0x00, //led1_aeu2/pwm2
    0x00, //led1_aeu2/pwm3
    0x00, //led1_aeu2/pwm4
    0x00, //led1_aeu2/pwm5
    0x0F, //led1_aeu2/slope_time1
    0x00, //led1_aeu2/slope_time2
    0x00, //led1_aeu2/pt1
    0x00, //led1_aeu3/pwm1
    0x00, //led1_aeu3/pwm2
    0x00, //led1_aeu3/pwm3
    0x00, //led1_aeu3/pwm4
    0x00, //led1_aeu3/pwm5
    0x00, //led1_aeu3/slope_time1
    0x00, //led1_aeu3/slope_time2
    0x00, //led1_aeu3/pt1
    0x00, //led2_pause time
    0x1F, //led2_playback times
    0x00, //led2_aeu1/pwm1
    0x00, //led2_aeu1/pwm2
    0xFF, //led2_aeu1/pwm3
    0xFF, //led2_aeu1/pwm4
    0x00, //led2_aeu1/pwm5
    0x2B, //led2_aeu1/slope_time1
    0x2E, //led2_aeu1/slope_time2
    0x00, //led2_aeu1/pt1
    0x00, //led2_aeu2/pwm1
    0x00, //led2_aeu2/pwm2
    0x00, //led2_aeu2/pwm3
    0x00, //led2_aeu2/pwm4
    0x00, //led2_aeu2/pwm5
    0x0F, //led2_aeu2/slope_time1
    0x00, //led2_aeu2/slope_time2
    0x00, //led2_aeu2/pt1
    0x00, //led2_aeu3/pwm1
    0x00, //led2_aeu3/pwm2
    0x00, //led2_aeu3/pwm3
    0x00, //led2_aeu3/pwm4
    0x00, //led2_aeu3/pwm5
    0x00, //led2_aeu3/slope_time1
    0x00, //led2_aeu3/slope_time2
    0x00, //led2_aeu3/pt1
    0x00, //led3_pause time
    0x00, //led3_playback times
    0x00, //led3_aeu1/pwm1
    0x00, //led3_aeu1/pwm2
    0x00, //led3_aeu1/pwm3
    0x00, //led3_aeu1/pwm4
    0x00, //led3_aeu1/pwm5
    0x00, //led3_aeu1/slope_time1
    0x00, //led3_aeu1/slope_time2
    0x00, //led3_aeu1/pt1
    0x00, //led3_aeu2/pwm1
    0x00, //led3_aeu2/pwm2
    0x00, //led3_aeu2/pwm3
    0x00, //led3_aeu2/pwm4
    0x00, //led3_aeu2/pwm5
    0x00, //led3_aeu2/slope_time1
    0x00, //led3_aeu2/slope_time2
    0x00, //led3_aeu2/pt1
    0x00, //led3_aeu3/pwm1
    0x00, //led3_aeu3/pwm2
    0x00, //led3_aeu3/pwm3
    0x00, //led3_aeu3/pwm4
    0x00, //led3_aeu3/pwm5
    0x00, //led3_aeu3/slope_time1
    0x00, //led3_aeu3/slope_time2
    0x00, //led3_aeu3/pt1
};
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

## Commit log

2025-01-22 KiCad PCB design for V1 of Berrythe hardware
    [10164359-00011LF.step, 5013310207.stp, 530470210-3DModel.STEP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]
2025-01-22 Code Composer studio project of Berrythe firmware
    Works as per requirement.
    Only pending issue is blockiness in blue light dimming.
    [batt_state.c, breathe_mode.c, low_batt_mode.c]
2025-01-29 Battery state check value is 2's power in ms
2025-01-29 Batt state enables use of ADC offset
2025-01-29 Breathe mode uses another sequence for blue exhale
    and uses 16 bit with gamma correction to reduce blockiness in fade in or out
    [breathe_mode.c]
2025-02-17 Initial version of the firmware readme. Button sensing is left to be explained.
2025-02-17 Add Graphviz Dot source in comment for the state machine and flow charts.
2025-02-18 Update Readme.md
    Update state machine and flow chart images based on Mermaid based description in Markdown
2025-02-18 Removed flow charts and state machine images - not needed now
2025-02-27 Update Readme.md
    Added color to some lines and changed 5V supply to one unit
2025-03-25 Create test jig 3D model for printing
    [Jig_PCB_holder_bottom.FCStd, Jig_PCB_holder_bottom.stl, Jig_PCB_holder_top.stl]
